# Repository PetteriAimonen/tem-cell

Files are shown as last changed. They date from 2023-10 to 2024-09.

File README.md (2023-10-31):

# Custom built TEM cell for EMC measurements

This repository contains FreeCAD and KiCad design files for a [TEM cell](https://en.wikipedia.org/wiki/TEM_cell)
with integrated [LISN](https://en.wikipedia.org/wiki/Line_Impedance_Stabilization_Network).

When combined with a spectrum analyzer, it can be used for EMC pretest measurements.

More construction details are available in [my blog article](http://essentialscrap.com/tem_cell/).

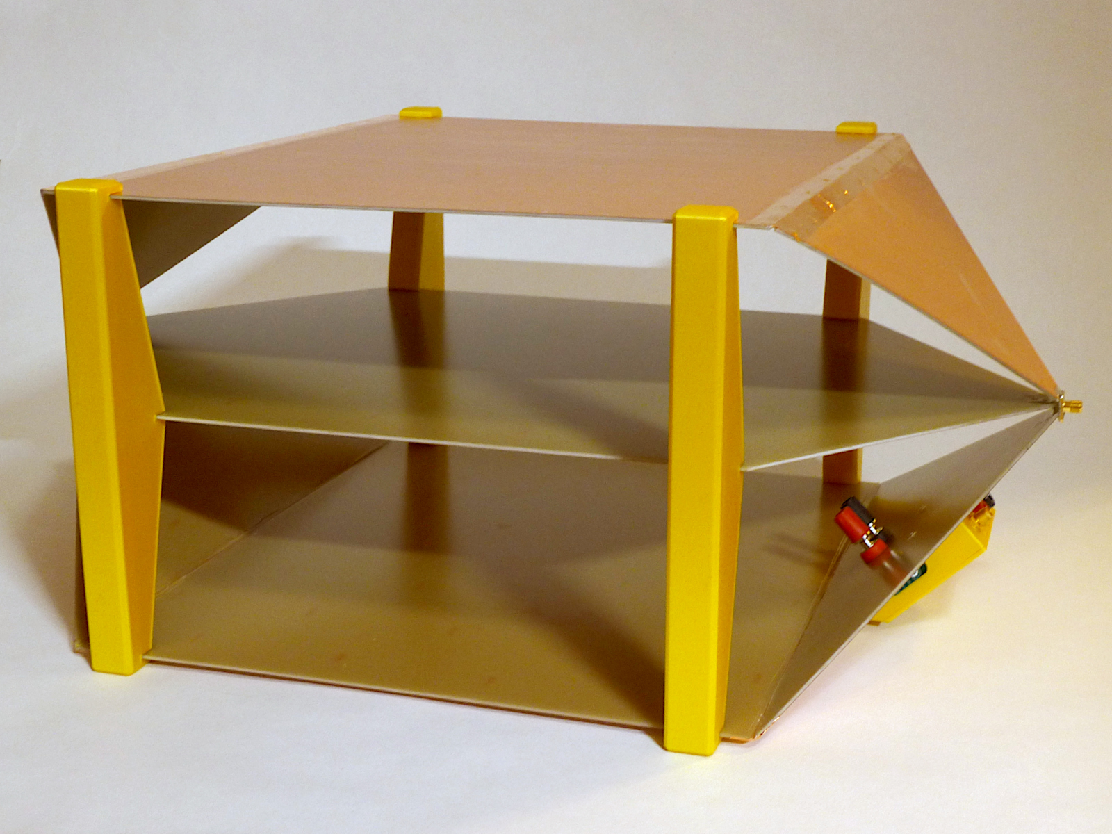
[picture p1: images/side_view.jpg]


## TEM cell structure

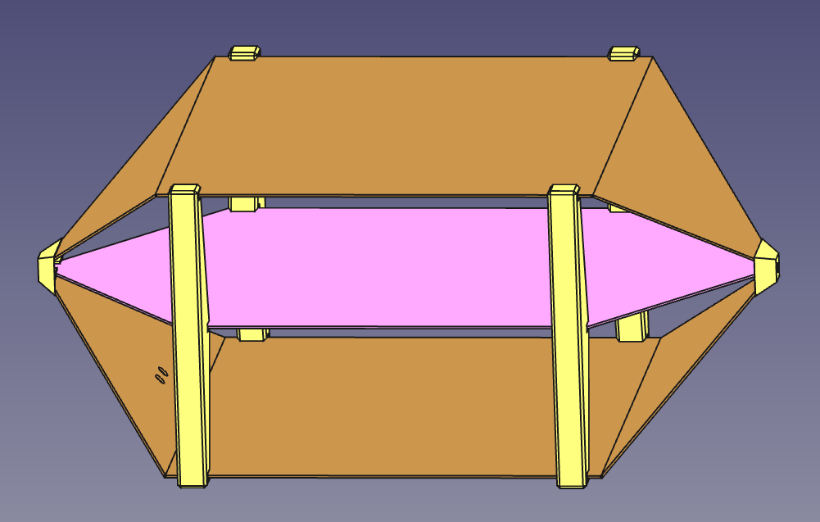
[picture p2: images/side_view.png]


The TEM cell consists of three conductive layers: shield on the top and bottom, and septum in the middle.
The width and spacing of the conductors determines the [characteristic impedance](https://en.wikipedia.org/wiki/Characteristic_impedance) of the transmission line.
The default dimensions are designed for an impedance of 50 ohms, matching most measurement equipment.

Any non-magnetic metal can be used for the construction.
The default thickness of 1.6 mm is set for commonly available PCB material.

Coaxial connectors are mounted at each end of the cell.
In normal operation one end is terminated with a 50 ohm resistor
and the other end is connected to spectrum analyzer or signal generator.

## Dimensions

The classic source for custom TEM cell builds is [Do-it-Yourself Fabrication of an Open TEM Cell for EMC Pre-compliance](http://eagle.chaosproject.com/sandbox/acstrial/newsletters/summer08/pp2.pdf) by Sandeep M. Satav et al, 2008. It provides the formula for characteristic impedance Z0 of the cell. Goal is to select dimensions so that Z0 equals 50 ohms, to facilitate connection to measurement instruments.

$$ Z_0 = \frac{94.15 \Omega}{\sqrt{\epsilon_r} \cdot \left[ \frac{w}{2d(1 - \frac{t}{2d})} + \frac{C_f}{0.0885 \cdot \epsilon_r} \right] } $$

For air as insulator (εr = 1) and thin material (t → 0), this can be simplified to:

$$ Z_0 = \frac{94.15 \Omega}{\frac{w}{2d} + \frac{C_f}{0.0885}} $$

with the parameters:

* **w**: Width of the septum
* **d**: Distance between septum and shield
* **Cf**: Fringe capacitance

The paper further provides value 0.053 pF/cm for the fringe capacitance, based
on earlier paper [Generation of Standard EM Fields Using TEM Transmission Cells](https://www.ieee.li/pdf/essay/generation_of_standard_em_fields_using_tem_transmission_cells.pdf) by Myron L. Crawford, 1974. However Satav's paper describes an open TEM cell (with two walls), while Crawford's paper describes a closed TEM cell (with four walls).

Open TEM cell dimensions calculated based on Cf = 0.053 result in a characteristic impedance 1.7 times higher than expected. Using scale models, I have determined that Cf = 0.03 is closer to the correct value for open TEM cells. Relative width of shields and septum affects this value and also uniformity of the electromagnetic field, but optimal configuration is yet unknown.

## Integrated LISN

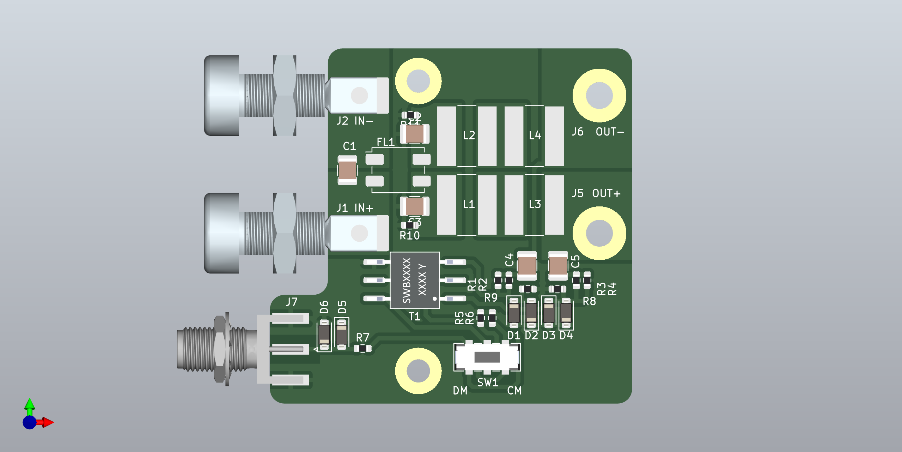
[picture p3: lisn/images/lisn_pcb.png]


[(LISN schematic)](lisn/images/lisn.pdf)

Optionally a LISN can be mounted on the outside of the TEM cell.
This is useful for providing a filtered power supply to the device being tested and for measuring conducted emissions.

The LISN is a nominally 50 µH design loosely following CISPR 16 standard, providing 50 ohm impedance to DUT.
It is suitable for pretesting use for DC-supplied devices with most EMC standards.

The LISN includes integrated DC block and clamping diodes to limit output to ±0.4 Vpk.
Attenuation at the output port is 10 dB.
A slide switch selects between common mode and differential mode measurement.

The LISN maximum current is determined by inductor selection and maximum voltage by capacitor ratings.
With the listed parts, maximum output current is 1.5 A and voltage 100 VDC.

## 3D printed support blocks and LISN enclosure

Correct distance between TEM cell shields and septum is maintained by side support blocks.
These should be printed at a low infill ration (5% recommended) to reduce their effect on the dielectric constant.

LISN enclosure is designed to mount on the tapered section.
Two binding posts go through the shield to provide a connection on the inside of the cell.
Banana jacks and SMA connector are used for connecting a power supply and spectrum analyzer.

## Parametric design

The design in `OpenTEMCell.FCStd` is a [FreeCAD](https://www.freecad.org/) parametric design file.
The critical dimensions can be modified in spreadsheet form and the 3D model will update to match.

One possible design is provided as generated files in subdirectory [Model_L500mm_W350mm_H200mm](Model_L500mm_W350mm_H200mm).

## Part recommendations

Wide variety of materials can be used for the construction.
I have listed below the materials I have used to construct the Model_L500mm_W350mm_H200mm version:

**TEM cell:**

|Item|Count|
|--|--|
| [FR4 PCB material, one sided, 610x457mm](https://www.tme.eu/fi/en/details/lam457x610e1.5/one-layer-laminates/) | 3 pcs |
| [Square flange SMA connector](https://www.tme.eu/fi/en/details/rf2-155-t-00-50-g/sma-smb-smc-connectors/adam-tech/) | 2 pcs |
| [SMA terminator](https://www.tme.eu/fi/en/details/132360/sma-smb-smc-connectors/amphenol-rf/) | 1 pcs |

**LISN:**

|Item|Count|
|--|--|
|Binding posts [CL1572](https://www.tme.eu/en/details/cl1572/4mm-banana-sockets/cliff/) (red) and [CL1575](https://www.tme.eu/en/details/cl1575/4mm-banana-sockets/cliff/) (black) | 2 pcs total |
| Banana connectors [108-0902-001](https://www.digikey.fi/en/products/detail/cinch-connectivity-solutions-johnson/108-0902-001/5929) (red) and [108-0903-001](https://www.digikey.fi/en/products/detail/cinch-connectivity-solutions-johnson/108-0903-001/5930) (black) | 2 pcs total |
| [SMA connector, edge mount](https://www.tme.eu/en/details/rf2145at1750ghdw/sma-smb-smc-connectors/adam-tech/rf2-145a-t-17-50-g-hdw/) | 1 pcs |
| [9 mm long M3 standoffs](https://www.tme.eu/en/details/tff-m3x9_dr113/metal-spacers/dremec/113x09/) | 2 pcs |
| [5 mm long M3 standoffs](https://www.tme.eu/en/details/tfm-m3x5_dr223/metal-spacers/dremec/223x05/) | 2 pcs |
| M3 countersunk screws | 2 pcs |
| [Parts listed in PCB BOM](lisn/gerbers/lisn-BOM.csv) | |

## Correlation to far-field measurements

[Spreadsheet](Model_L500mm_W350mm_H200mm/CorrectionFactors.ods) is provided for calculating correction factor for converting TEM cell measurements in dBµV to far field measurements in dBµV/m. The correction factor depends on frequency.

The values are used in place of antenna factor: they simply added to the dBµV reading of the spectrum analyzer at each frequency. The calculation is based on formula:

$$ 20 \cdot \log_{10}\left[ \frac{η_0 \cdot h}{Z_0 \cdot λ \cdot r} \right] $$

with the parameters:

* η0: [free space impedance](https://en.wikipedia.org/wiki/Impedance_of_free_space) 377 Ω
* Z0: TEM cell characteristic impedance 50 Ω
* h: TEM cell vertical distance between septum and shield (0.1 m for example design)
* r: Far-field measurement distance (3 m for most EMC standards)
* λ: Wavelength of the frequency (λ = c / f)

The formula is based on [Antenna Gain-Factor Equivalent for TEM Cells](https://tsapps.nist.gov/publication/get_pdf.cfm?pub_id=31708) by Perry F. Wilson, 2004.
Ideal isotropic [antenna factor](https://en.wikipedia.org/wiki/Antenna_factor) is used as the equivalent far field measurement antenna for converting into field strength units.

**NOTE: This application of the formula is my own interpretation of the source material.
It may be entirely incorrect. In any case, significant uncertainty remains because DUT geometry affects how effectively fields couple into TEM cell vs. into far field radiation.**

## TinySA Ultra configuration

[Preset configuration file](Model_L500mm_W350mm_H200mm/TinySAUltra_Preset.prs) is provided for [TinySA Ultra](https://www.tinysa.org/) to simplify measurements.

When applied, the preset configures green trace as correction factor table and subtracts it from the measurement traces. Output readings will approximate dBµV/m. Yellow trace is live measurement and purple trace is maximum level hold. Red trace is example of typical radiated emission limits, actual values will depend on applicable standard.

The spectrum analyzer settings used do not match any of the established EMC standards.
To achieve high scanning speed, a large resolution bandwidth and small dwell time of about 0.2 ms is used.
The detector is closest to average measurement type, though the maximum hold will retain the peak value if it hits the dwell time window.
These limitations will result in significant inaccuracies when measuring narrow-band or pulsed emissions.

Signal coupling in TEM cell will depend both on the magnetic and electric field orientations.
One technique is to rotate the DUT into different orientations and let the maximum hold capture the largest emissions. At the end, power down DUT so that you can compare background noise against any spikes from the device.

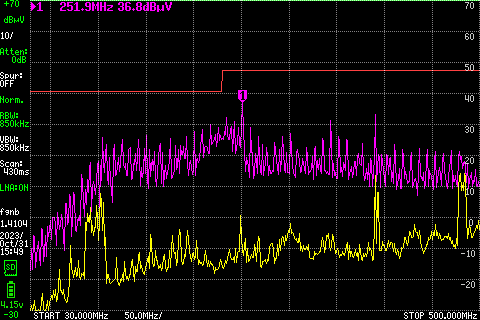
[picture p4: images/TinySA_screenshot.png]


## License

All the design materials are available under CC-BY-4.0 license.
Preferred attribution:

> © 2023 Petteri Aimonen. Licensed under CC-BY-4.0. https://essentialscrap.com/

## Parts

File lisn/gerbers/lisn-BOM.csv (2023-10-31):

Reference | Value | Footprint | Notes | PartNumber | Qty
C1-C5 | 1µF | Capacitor_SMD:C_1210_3225Metric | 100 V 1µF 1210 X7R ceramic capacitor | C1210J105K1RAC7800 | 5
D1-D4 | DSS16 | Diode_SMD:D_SOD-123 | SOD123 schottky diode, > 2A pulse current capability | DSS16U | 4
D5, D6 | BAT54GW | Diode_SMD:D_SOD-123 | SOD123 schottky diode, low forward voltage | BAT54GW | 2
FL1 | CM7060 | Inductor_SMD:L_CommonModeChoke_TDK_ACM7060 | Common mode choke | CM7060M132R-10 | 1
J1 | IN+ | footprints:BANANA_JACK_108-0902-001 | Banana connector, soldered to PCB and screwed into enclosure | 108-0902-001 | 1
J2 | IN- | footprints:BANANA_JACK_108-0902-001 | Banana connector, soldered to PCB and screwed into enclosure | 108-0902-001 | 1
J3, J4 | GND | MountingHole:MountingHole_3.2mm_M3_Pad | Mounting screws and ground connection |  | 2
J5 | OUT+ | MountingHole:MountingHole_3.7mm_Pad | Binding post for power output | CL1572 | 1
J6 | OUT- | MountingHole:MountingHole_3.7mm_Pad | Binding post for power output | CL1575 | 1
J7 | SMA | Connector_Coaxial:SMA_Amphenol_132289_EdgeMount | Edge mount SMA connector | RF2-145A-T-17-50-G-HDW | 1
L1-L4 | 22µH | Inductor_SMD:L_Bourns-SRN8040_8x8.15mm | 22µH to 27µH inductor, high saturation current | SDR0805-220ML | 4
R1-R4 | 50 | Resistor_SMD:R_0603_1608Metric | Generic 0603 1% resistor |  | 4
R5, R6 | 82 | Resistor_SMD:R_0603_1608Metric | Generic 0603 1% resistor |  | 2
R7 | 30 | Resistor_SMD:R_0603_1608Metric | Generic 0603 1% resistor |  | 1
R8, R9 | 68 | Resistor_SMD:R_0603_1608Metric | Generic 0603 1% resistor |  | 2
R10, R11 | 100k | Resistor_SMD:R_0603_1608Metric | Generic 0603 1% resistor |  | 2
SW1 | DPDT | footprints:SW_DPDT_CK_JS202011JCQN | Slide switch for output mode selection | JS202011JCQN | 1
T1 | SWB2010 | footprints:SWB2010-SMLD | SWB1010-SMLD and SWB3010-SMLD are compatible | SWB2010-SMLD | 1

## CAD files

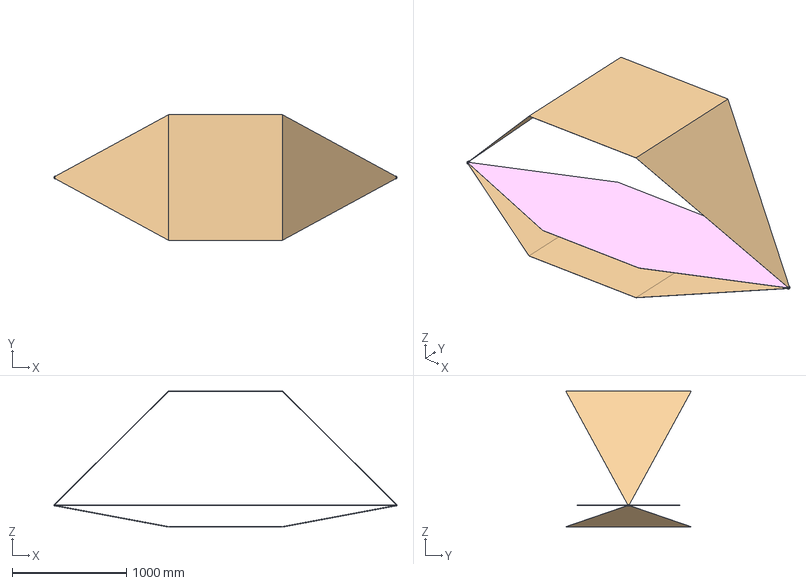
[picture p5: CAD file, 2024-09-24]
AsymmetricTEMCell.FCStd
3006.0 x 1100.0 x 1190.0 mm
Septum
UpperShield
LowerShield
EndHolder001
EndHolder (mirrored)

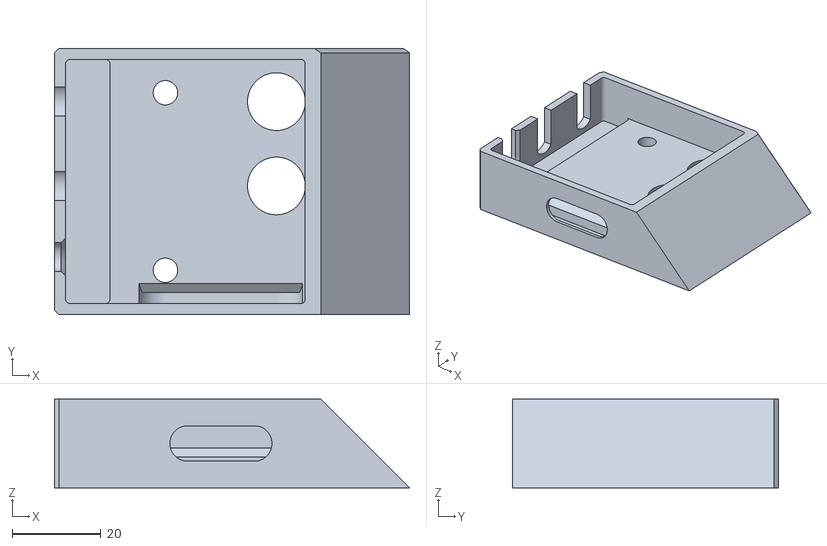
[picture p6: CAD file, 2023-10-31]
lisn_enclosure/lisn_enclosure-EnclosureBottom.stl
80.0 x 60.0 x 20.0

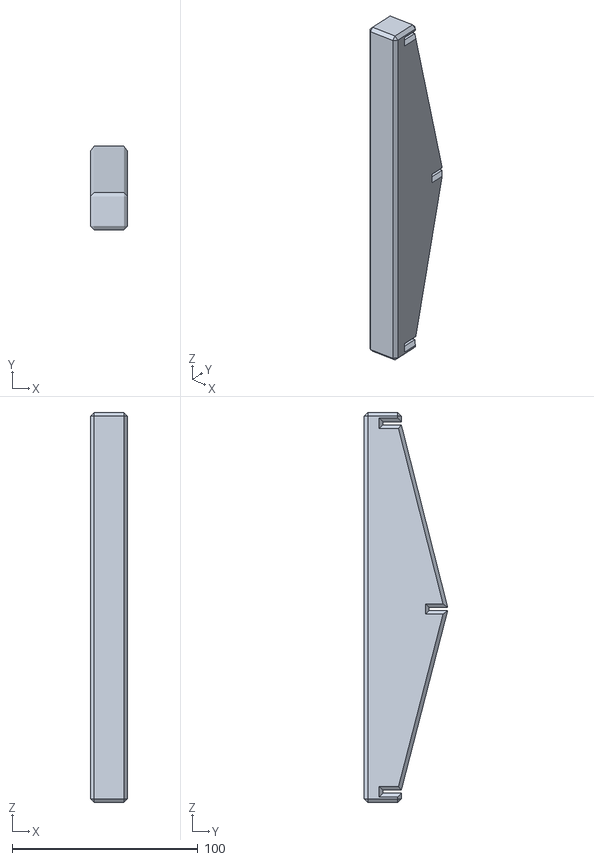
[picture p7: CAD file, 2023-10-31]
Model_L500mm_W350mm_H200mm/OpenTEMCell-SideHolder.stl
20.0 x 45.0 x 210.0

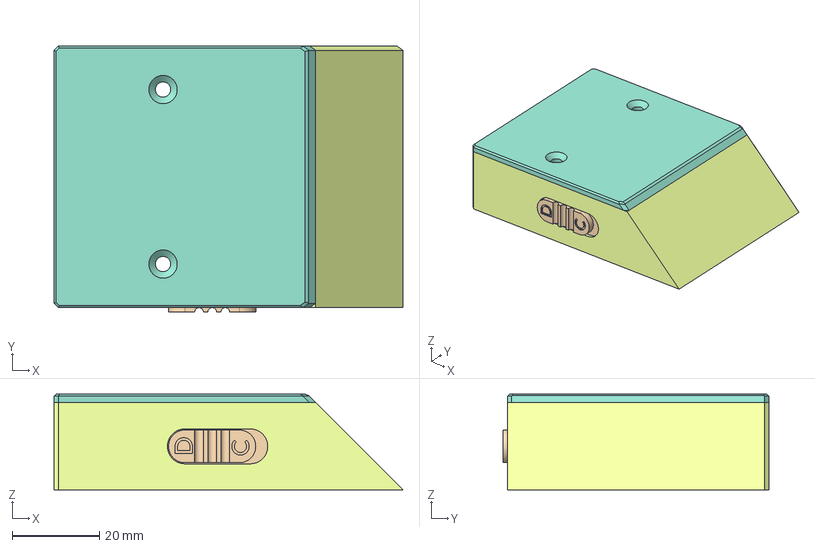
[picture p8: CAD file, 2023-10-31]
lisn_enclosure/lisn_enclosure.FCStd
80.0 x 61.0 x 22.0 mm
EnclosureBottom001
SwitchSlider001
EnclosureLid001

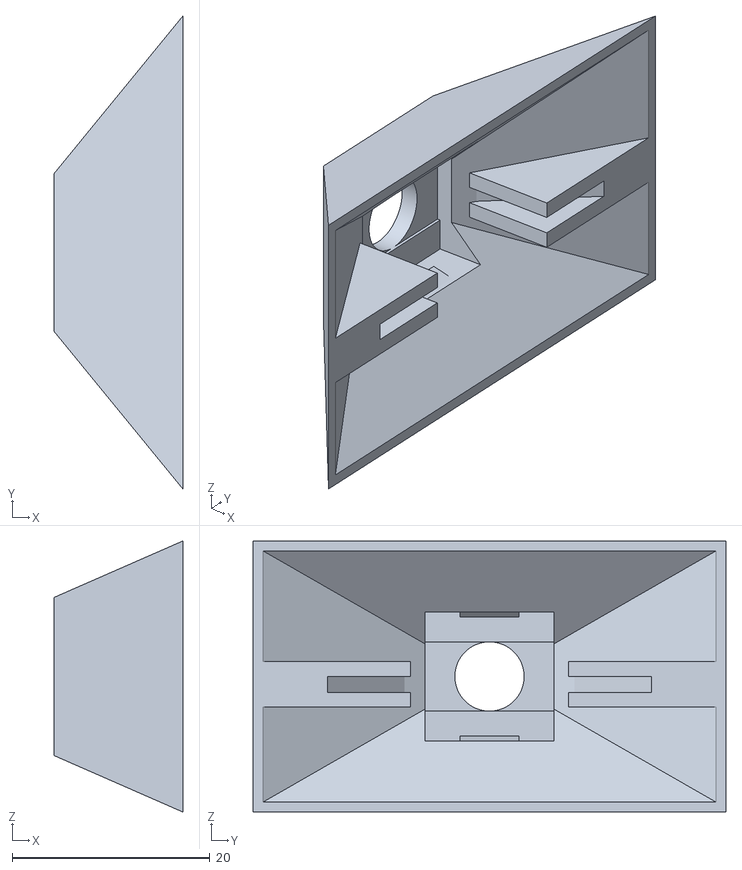
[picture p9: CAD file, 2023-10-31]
Model_L500mm_W350mm_H200mm/OpenTEMCell-EndHolder.stl
13.0 x 47.8 x 27.4

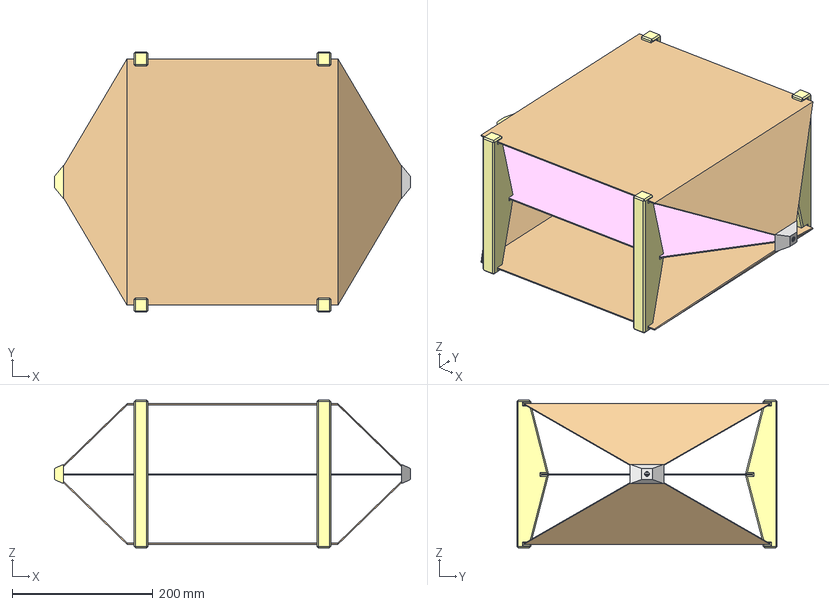
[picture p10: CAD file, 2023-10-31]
OpenTEMCell.FCStd
506.0 x 370.0 x 210.0 mm
SideHolder1
SideHolder4 (mirror)
SideHolder3 (mirror)
SideHolder2 (mirror)
Septum
UpperShield
LowerShield
EndHolder001
EndHolder (mirrored)

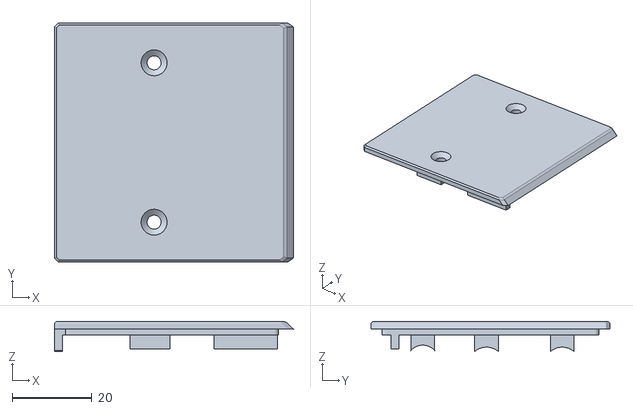
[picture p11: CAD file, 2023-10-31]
lisn_enclosure/lisn_enclosure-EnclosureLid.stl
60.0 x 60.0 x 7.65

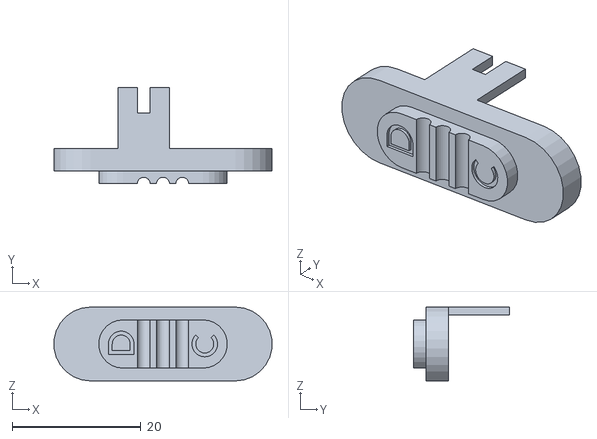
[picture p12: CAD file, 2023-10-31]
lisn_enclosure/lisn_enclosure-SwitchSlider.stl
33.9 x 15.0 x 11.5

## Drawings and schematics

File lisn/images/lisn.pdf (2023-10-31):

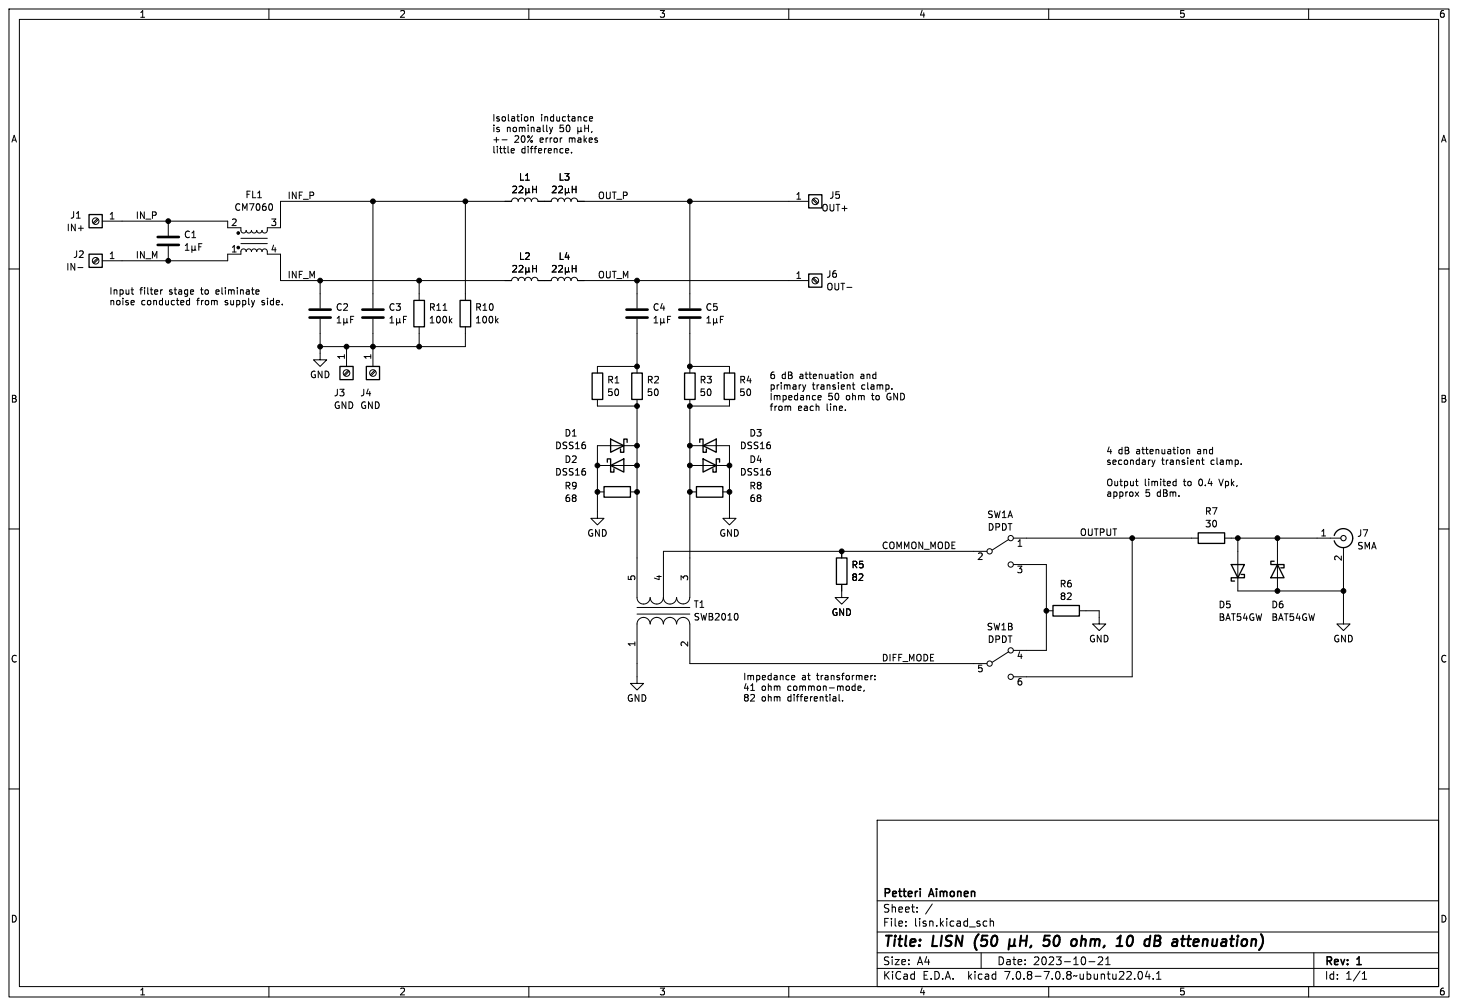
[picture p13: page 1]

Input filter stage to eliminate

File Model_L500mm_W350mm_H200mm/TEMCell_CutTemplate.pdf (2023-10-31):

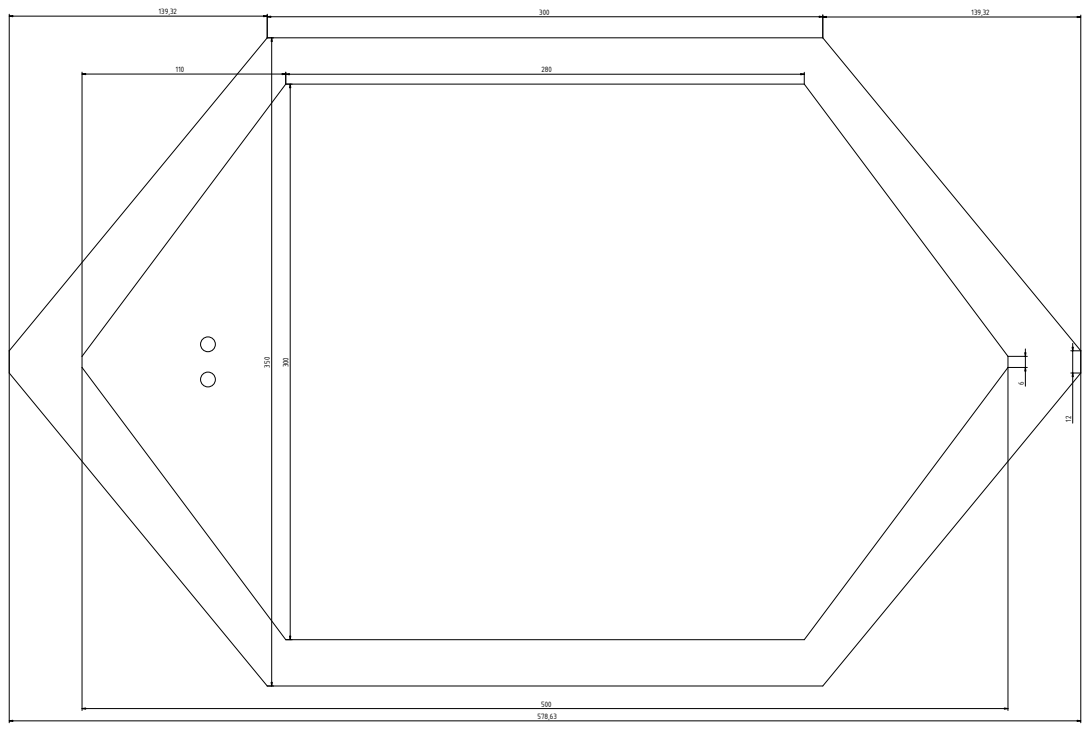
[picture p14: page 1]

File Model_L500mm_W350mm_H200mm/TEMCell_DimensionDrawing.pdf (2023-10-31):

# Open TEM cell design parameters (generated from OpenTEMCell.FCStd)

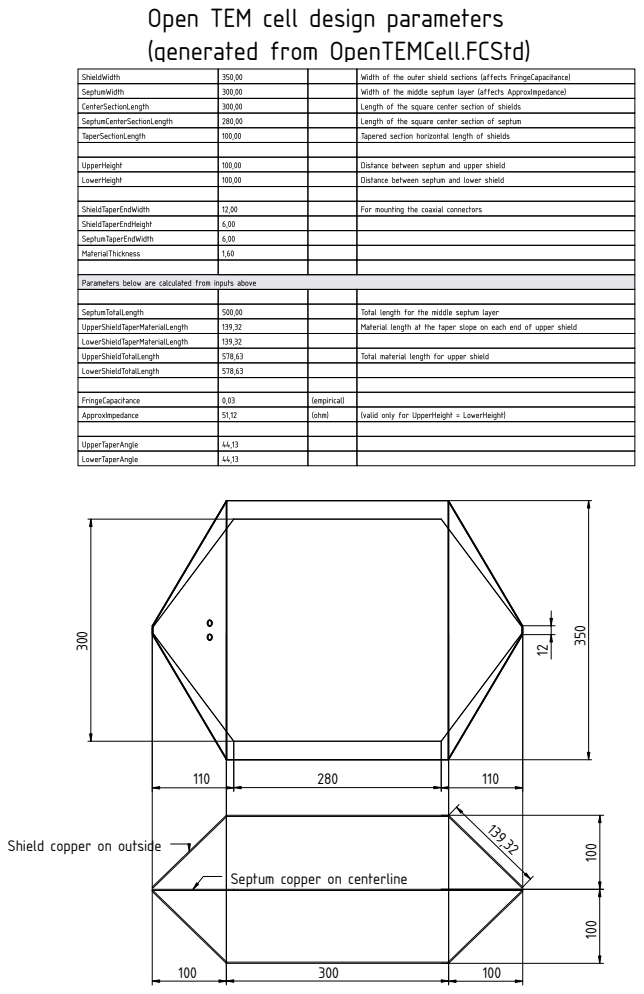
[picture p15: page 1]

Shield copper on outside

Septum copper on centerline

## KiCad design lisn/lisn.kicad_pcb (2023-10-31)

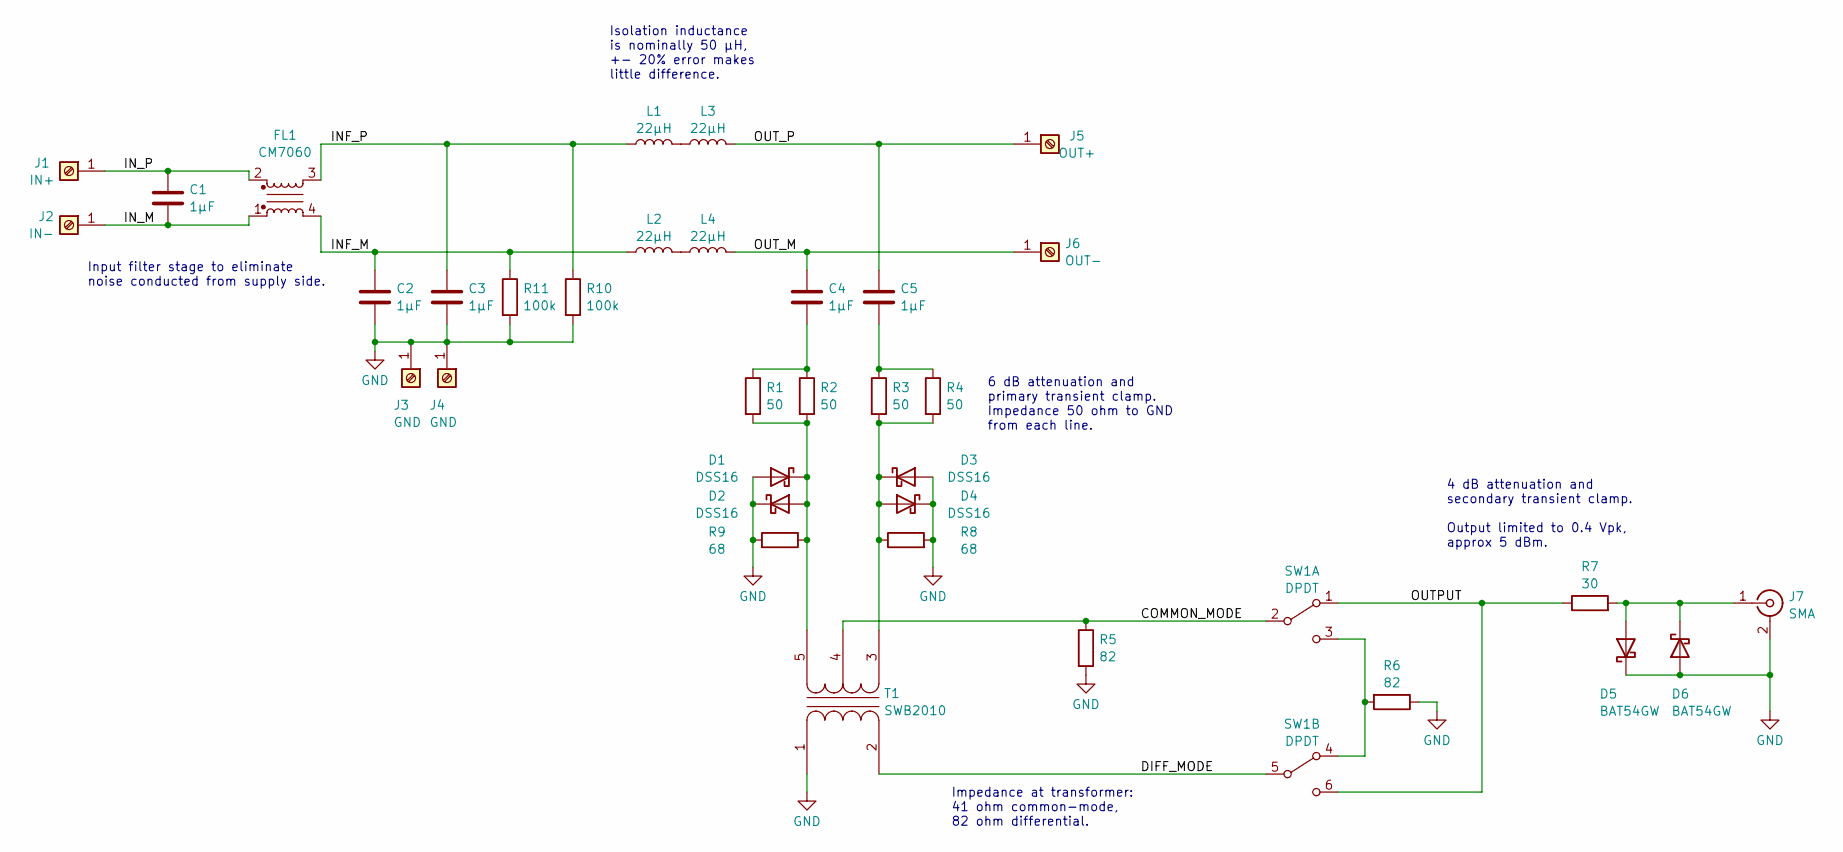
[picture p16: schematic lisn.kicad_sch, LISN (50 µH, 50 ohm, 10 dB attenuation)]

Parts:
C1, C2, C3, C4, C5: 1µF; C_1210_3225Metric; PartNumber C1210J105K1RAC7800
D1, D2, D3, D4: DSS16; D_SOD-123; PartNumber DSS16U
D5, D6: BAT54GW; D_SOD-123; PartNumber BAT54GW
FL1: CM7060; L_CommonModeChoke_TDK_ACM7060; PartNumber CM7060M132R-10
J1: IN+; BANANA_JACK_108-0902-001; PartNumber 108-0902-001
J2: IN-; BANANA_JACK_108-0902-001; PartNumber 108-0902-001
J3, J4: GND; MountingHole_3.2mm_M3_Pad
J5: OUT+; MountingHole_3.7mm_Pad; PartNumber CL1572
J6: OUT-; MountingHole_3.7mm_Pad; PartNumber CL1575
J7: SMA; SMA_Amphenol_132289_EdgeMount; PartNumber RF2-145A-T-17-50-G-HDW
L1, L2, L3, L4: 22µH; L_Bourns-SRN8040_8x8.15mm; PartNumber SDR0805-220ML
R1, R2, R3, R4: 50; R_0603_1608Metric
R5, R6: 82; R_0603_1608Metric
R7: 30; R_0603_1608Metric
R8, R9: 68; R_0603_1608Metric
R10, R11: 100k; R_0603_1608Metric
SW1: DPDT; SW_DPDT_CK_JS202011JCQN; PartNumber JS202011JCQN
T1: SWB2010; SWB2010-SMLD; PartNumber SWB2010-SMLD

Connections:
/COMMON_MODE: R5.1, SW1.2 (B), T1.4 (SC)
/DIFF_MODE: SW1.5 (B), T1.2 (AB)
/INF_M: C2.1, FL1.4, L2.1, R11.1
/INF_P: C3.1, FL1.3, L1.1, R10.1
/IN_M: C1.2, FL1.1, J2.1
/IN_P: C1.1, FL1.2, J1.1
/OUTPUT: R7.1, SW1.1 (A), SW1.6 (C)
/OUT_M: C4.1, J6.1, L4.2
/OUT_P: C5.1, J5.1, L3.2
GND: C2.2, C3.2, D1.2 (A), D2.1 (K), D3.2 (A), D4.1 (K), D5.1 (K), D6.2 (A), J3.1, J4.1, J7.2 (Ext), R5.2, R6.1, R8.2, R9.2, R10.2, R11.2, T1.1 (AA)
unnamed: C4.2, R1.1, R2.1
unnamed: C5.2, R3.1, R4.1
unnamed: D1.1 (K), D2.2 (A), R1.2, R2.2, R9.1, T1.5 (SB)
unnamed: D3.1 (K), D4.2 (A), R3.2, R4.2, R8.1, T1.3 (SA)
unnamed: D5.2 (A), D6.1 (K), J7.1 (In), R7.2
unnamed: L1.2, L3.1
unnamed: L2.2, L4.1
unnamed: R6.2, SW1.3 (C), SW1.4 (A)

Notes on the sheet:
Impedance at transformer: 41 ohm common-mode, 82 ohm differential.
4 dB attenuation and secondary transient clamp. Output limited to 0.4 Vpk, approx 5 dBm.
6 dB attenuation and primary transient clamp. Impedance 50 ohm to GND from each line.
Input filter stage to eliminate noise conducted from supply side.
Isolation inductance is nominally 50 µH, +- 20% error makes little difference.

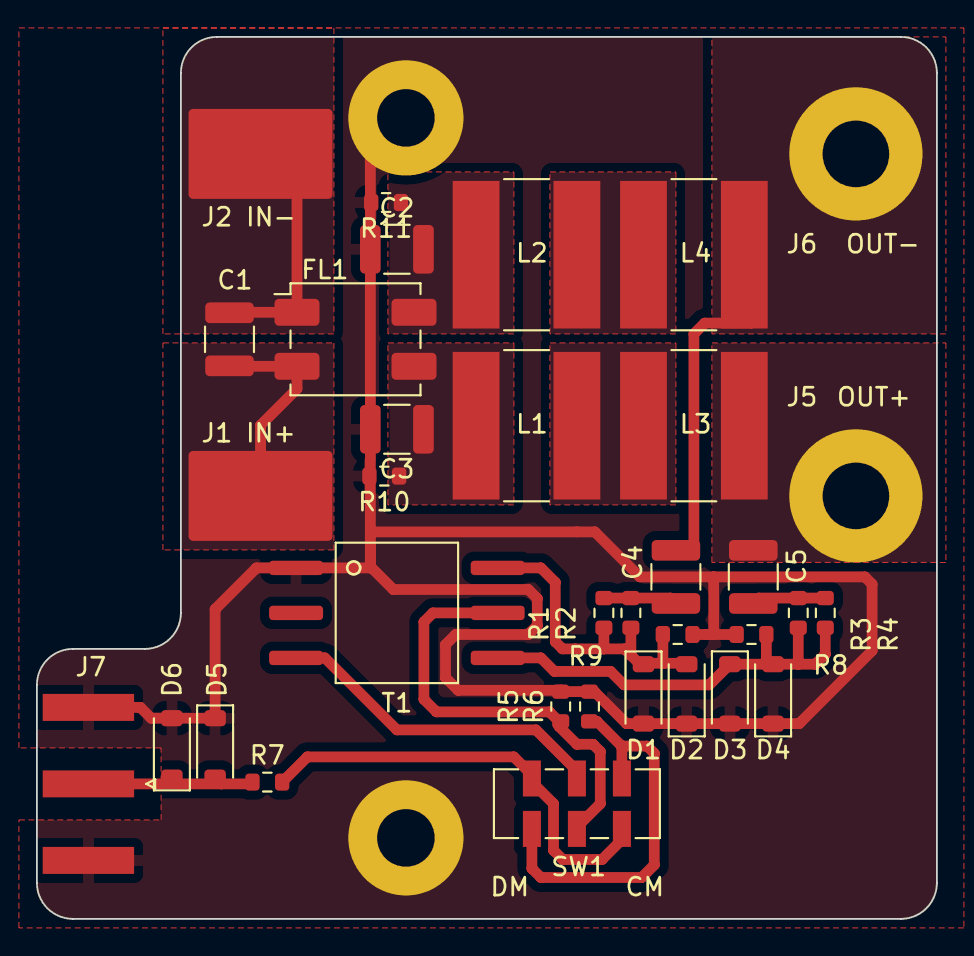
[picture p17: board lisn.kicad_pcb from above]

Board: 2 copper layers, 50.0 x 49.0 mm, 36 parts (0 on the bottom side), 18 nets.

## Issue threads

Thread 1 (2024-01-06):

Correlation to far-field measurements

thaanstad, 2024-01-06:
Can you please provide some background and intermediate calculation steps for the Correlation to far-field measurements equation that you derived using "ANTENNA GAIN-FACTOR EQUIVALENT FOR TEM CELLS".  In your experience has this been a reasonable correlation to EMC testing in a RF chamber?

Thanks for all the info!  I'm looking forward to building a TEM cell.

PetteriAimonen, 2024-01-06:
I don't have much experience with correlating the results yet. I do know that one product that barely passed testing is also close to the limit line I ended up with for TEM cell measurements. But with the effects from orientation, resolution bandwidth, frequency dependence, effect of cables etc, it is not clear how close one could hope to get.

As for the formula

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

I started with the equations:

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

Divide second row (FAR) by first row (TEM) and you get:

$$\frac{P_{FAR}}{P_{TEM}} = \frac{g_r (\frac{1}{r})^2}{(\frac{4\pi Z_0}{η_0}) (\frac{1}{h})^2} = \frac{g_r h^2 η_0}{4\pi Z_0 r^2}$$

Then from [Wikipedia](https://en.wikipedia.org/wiki/Antenna_factor) take the ideal isotropic antenna factor (antenna gain G = 1 for isotropic antenna). Note that it is in terms of voltage, so to apply it to the power ratio we should square it.

$$\sqrt{g_r} = \sqrt{\frac{η_0}{Z_0 \times \frac{\lambda^2}{4\pi}}} = \sqrt{\frac{η_0 4\pi}{Z_0 \lambda^2}} $$

Combining these two equations gives:

$$\frac{P_{FAR}}{P_{TEM}} = \frac{h^2 η_0^2}{Z_0^2 r^2 \lambda^2}$$

Then take square root again to get from power ratio to voltage ratio. And 20 * log10() to convert from voltage ratio to dB.

I do hope I haven't made some silly mistake somewhere. At least the units check out :)

Various EMC standards have all kinds of test setups, e.g. semi-anechoid room or open air test site has a reflection from ground while fully anechoid room does not. And the antennas used are dipoles instead of isotropic. But all of these add up to a few dB at most, which is probably irrelevant for the kind of accuracy we can even hope for here.

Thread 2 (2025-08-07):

TinySA version and preset

rupraph, 2025-08-07:
First, thank you so much for sharing this amazing work !
I also built one !

However I am struggling in setting up the TinySA and the correction factor to perform a proper measurement that has some meaning.
Indeed, the preset file does not seam to work anymore with more recent firmware. I have been trying to recreate your preset but can't seam to obtain similar results.

I have been trying to use your table
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
 Added -(columnC) in a trace and substracted it from the measuring trace. (don't mind of the speed too much for now)
Is this correct and only important thing to do to obtain correct magnitude readings ?

I could also downgrade my firmware if you let me know which version you used.

Thanks in advance !

PetteriAimonen, 2025-08-07:
Yeah, that's the basic idea.

My version is tinySA4_v1.4-104-gf4ca852, Jul 16 2023 10:26:46.

rupraph, 2025-08-08:
Preset cannot be attached. But it seems zip files are ok :)

[TEM-CELL-PRE-OK-FW-14201.prs.zip](https://github.com/user-attachments/files/21686529/TEM-CELL-PRE-OK-FW-14201.prs.zip)

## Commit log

2023-10-14 Initial design
    [end_holder.FCStd, end_holder.stl, side_holder.FCStd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]
2023-10-20 Add LISN PCB and enclosure
    [end_holder.FCStd, end_holder.stl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]
2023-10-21 Enclosure lid small changes
    [lisn_enclosure-EnclosureLid.stl, lisn_enclosure.FCStd]
2023-10-21 Update LISN PCB
    [end_holder.FCStd, end_holder.stl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]
2023-10-31 Add parametric FreeCAD design, add README.
    [CorrectionFactors.ods, OpenTEMCell-EndHolder.stl, OpenTEMCell-SideHolder.stl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]
2023-10-31 Better clearance for installing LISN mode switch slider
    [lisn_enclosure-EnclosureBottom.stl, lisn_enclosure-EnclosureLid.stl, lisn_enclosure-SwitchSlider.stl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]
2023-10-31 Add note about dimensions
    [OpenTEMCell.FCStd]
2024-09-24 Add asymmetric TEM cell design file
    [AsymmetricTEMCell.FCStd]
